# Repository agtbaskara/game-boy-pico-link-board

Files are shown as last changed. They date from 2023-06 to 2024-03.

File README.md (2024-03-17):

# USB TO GAMEBOY LINK CABLE ADAPTER
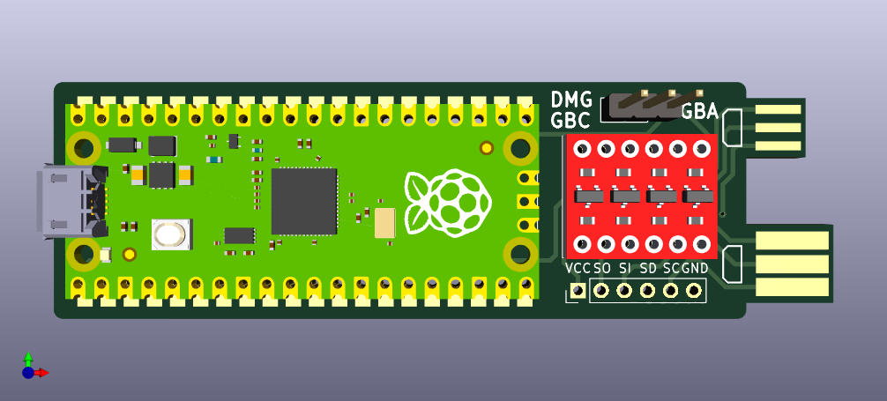
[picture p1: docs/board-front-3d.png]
Board 3D Render


An Open-Source USB to Gameboy Link Cable Adapter for Raspberry Pi Pico. Designed with components that are easy to source and solder.

Based on stacksmashing Gameboy Link adapter: https://www.youtube.com/watch?v=KtHu693wE9o

# Schematic

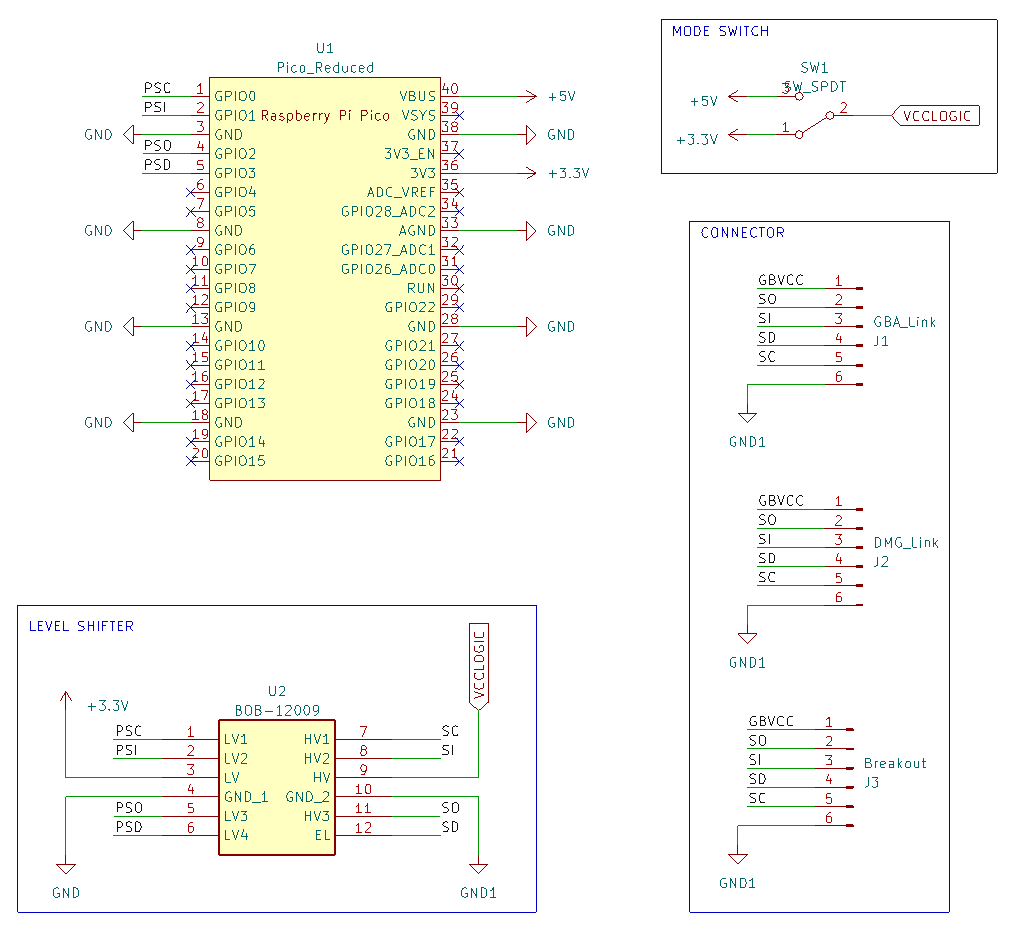
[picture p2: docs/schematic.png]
Schematic


# Required Components

| Reference | Part Number | Description |
|-|-|-|
| U1 | [Raspberry Pi Pico](https://www.raspberrypi.com/products/raspberry-pi-pico/) | Clones are compatible |
| U2 | [BOB-12009](https://www.sparkfun.com/products/12009) | Sparkfun Bi-Directional Logic Level Converter, clones are compatible |
| SW1 | [SS12D00-G3](https://www.amazon.com/Tnuocke-Vertical-Position-Switches-SS12D00-G3/dp/B099MRCDG8) | 3 Pin SPDT Switch with 1" (2.54mm) Pitch |

If you want to use pin jumper instead of switch you can use:

| Reference | Part Number | Description |
|-|-|-|
| SW1 | [Pin Header](https://www.amazon.com/dp/B07PKKY8BX) | 1x3 2.54mm Male Pin Header |
| - | [Pin Jumper](https://www.amazon.com/dp/B077957RN7) | 2.54mm Pin Jumper, harvest from old motherboard or hardrive |

**Attached links are for reference only, you can use any equivalent parts.**

**List of tested components** [Tested Components List](COMPONENTS.md)

# How to Order Board

To order a board, use the `gerbers.zip` from the release page or generate one yourself. You can order from your favourite PCB manufacturer ([JLCPCB](https://jlcpcb.com/), [PCBWay](https://www.pcbway.com/), etc.).

**Use 1.2mm PCB thickness.**

You can choose any colour for the Solder Mask and Silkscreen. For the Surface Finish, ENIG is recommended.

# How to Assemble Board

1. Trim the Link Cable connectors width on the board to the appropriate size using a file tool or sandpaper
2. Solder pin header to Raspberry Pi Pico and Level Shifter module. Use a breadboard for easier soldering
3. Solder Raspberry Pi Pico and Level Shifter module to the board
4. Cut the excessive pin using a nipper tool
5. Solder the 1x3 Pin Header to the board, and place the Pin Jumper
6. Flash firmware to your Raspberry Pi Pico (see [Compatibility](#Compatibility))

# How to Use Board

Connect the board to your PC, and connect the board to your Gameboy using a Link Cable.

For Gameboy/Gameboy Color game, place the pin jumper on the DMG/GBC side. For Gameboy Advance game, place the pin jumper on the GBA side.

**Be aware Gameboy/Gameboy Color mode uses 5V logic, while Gameboy Advance mode uses 3.3V logic. Make sure your pin jumper is placed on the correct side to avoid any damage.**

# Compatibility

This board is compatible with the following firmware:
- https://github.com/Lorenzooone/gb-link-firmware-reconfigurable (Recommended Firmware)
- https://github.com/stacksmashing/gb-link-firmware
- https://github.com/stacksmashing/gb-link-printer
- https://github.com/Lorenzooone/PokemonGB_Online_Trades
- https://github.com/dj505/GBPrinterEmu
- https://github.com/Squaresweets/GBPrinter-discord-bot
- https://github.com/KuestenKeks/pc-to-gb-printer

With some modification, it should be compatible with other firmware as well, such as:
- https://github.com/untoxa/pico-gb-printer

# References

- Raspberry Pi Pico Footprint: https://github.com/ncarandini/KiCad-RP-Pico
- Logic Level Converter (BOB-12009) Footprint: https://www.snapeda.com/parts/BOB-12009/SparkFun%20Electronics/view-part/
- Gameboy Link Connector Footprint: https://github.com/Palmr/gb-link-cable
- 1.2mm PCB Thickness, based on: https://hackaday.io/project/12932-game-link-online/log/43999-received-the-breakout-boards

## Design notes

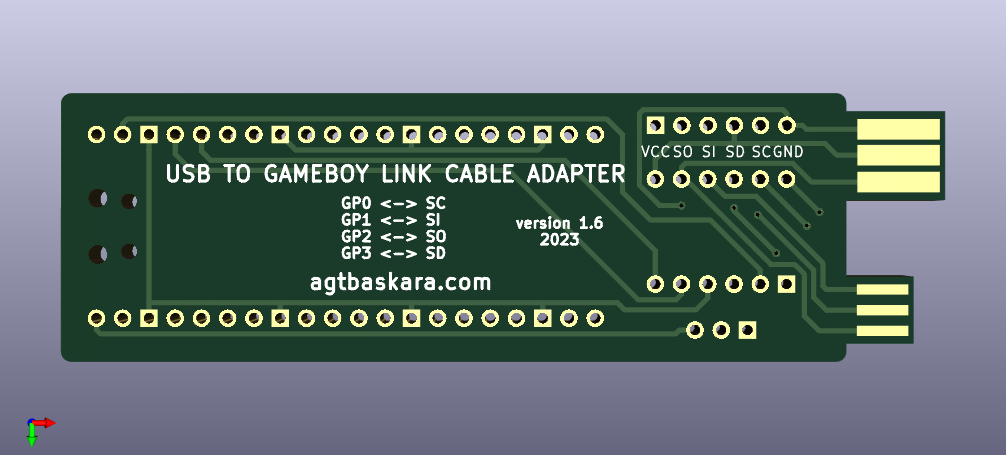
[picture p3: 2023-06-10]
docs/board-back-3d.png

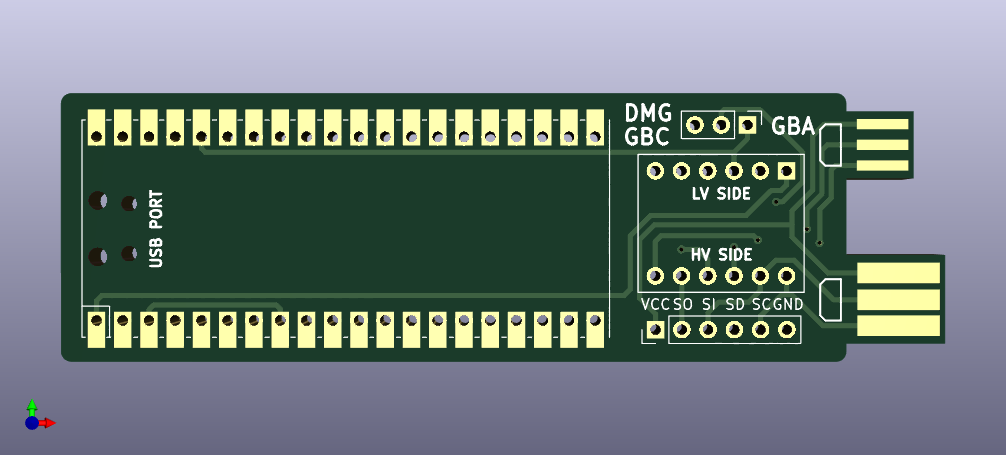
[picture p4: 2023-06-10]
docs/board-front-3d-bare.png

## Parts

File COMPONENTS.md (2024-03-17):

# Tested Components List

This page contains the components that have been tested with the adapter board. This page is based on my personal test and also data from the community.

Please contribute if you found new compatible/incompatible components.

## Raspberry Pi Pico

In theory every raspberry pi pico clones with the same pinout should work.

| Compatible | Pictures | Shop/Datasheet Link | Description |
|-|-|-|-|
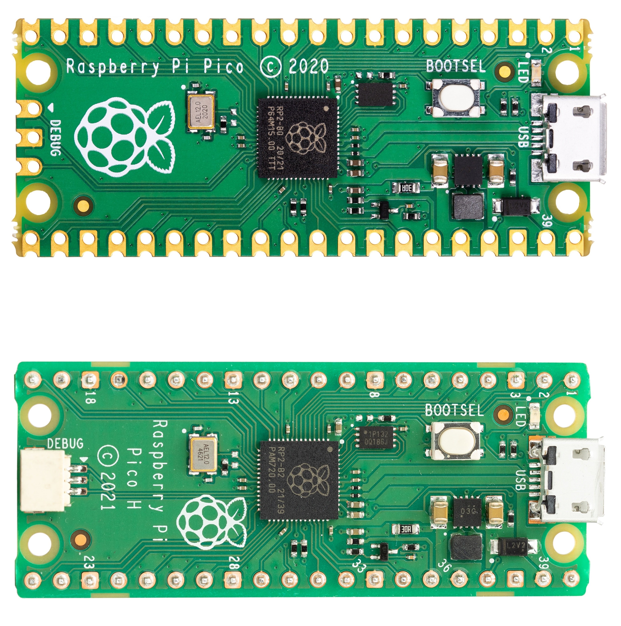
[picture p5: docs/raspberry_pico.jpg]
PICO
| Yes |  | [Link](https://www.raspberrypi.com/products/raspberry-pi-pico/) | Original Raspberry Pi Pico |
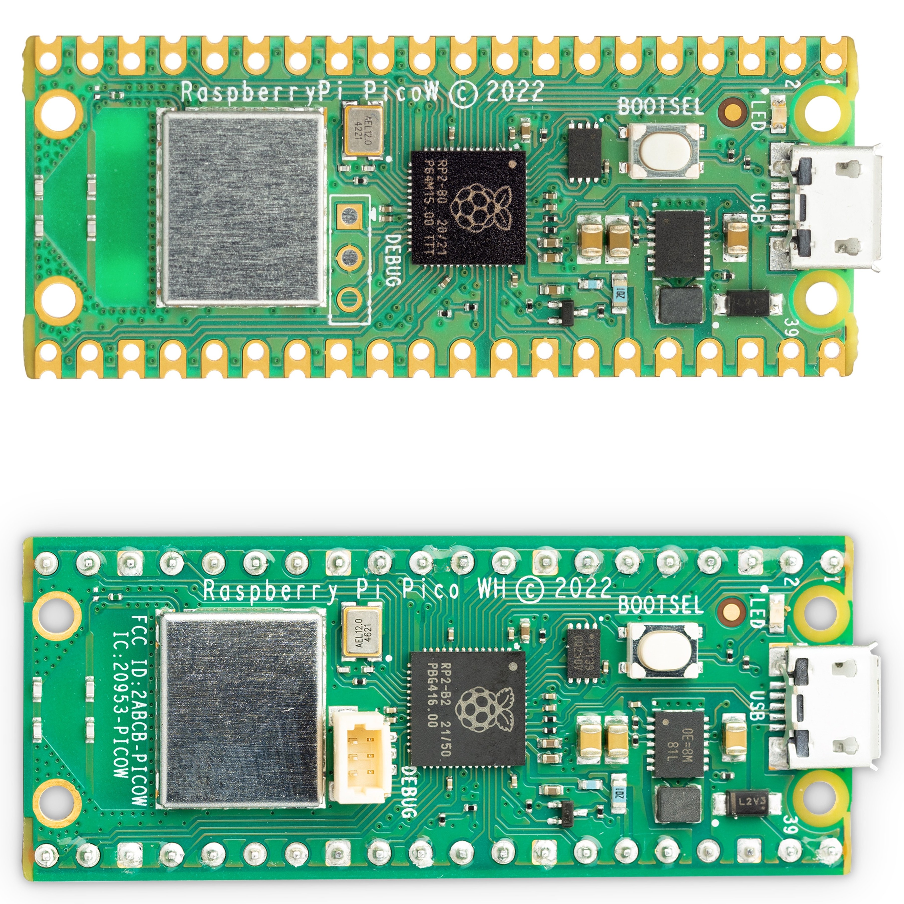
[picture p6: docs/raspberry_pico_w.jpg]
PICO
| Yes |  | [Link](https://www.raspberrypi.com/products/raspberry-pi-pico/) | Original Raspberry Pi Pico W|
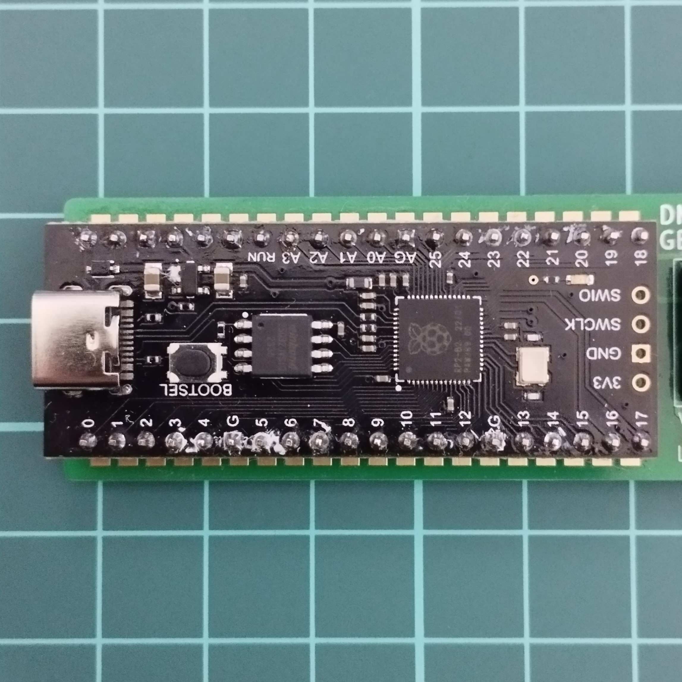
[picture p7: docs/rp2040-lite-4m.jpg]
| Yes |  | [Link](https://www.aliexpress.com/item/1005003928558306.html) | RP2040 Lite Black TYPE-C 4M|

## Level Shifter

Becareful of bad quality clones.

| Compatible | Pictures | Shop/Datasheet Link | Description |
|-|-|-|-|
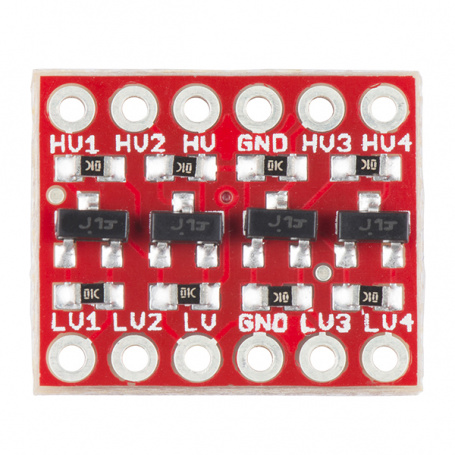
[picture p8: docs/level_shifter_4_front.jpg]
Level Shifter
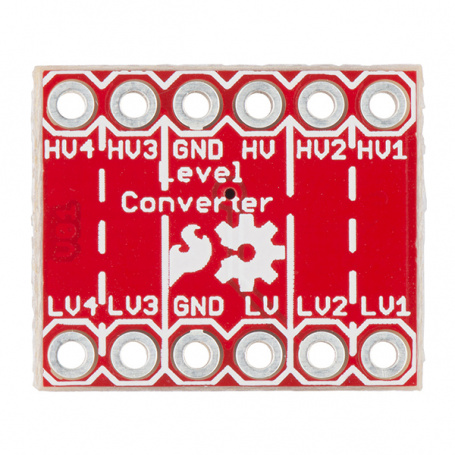
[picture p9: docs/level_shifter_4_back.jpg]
Level Shifter
| Yes |    | [Link](https://www.sparkfun.com/products/12009) | Original Sparkfun 4 Channel Level Shifter |
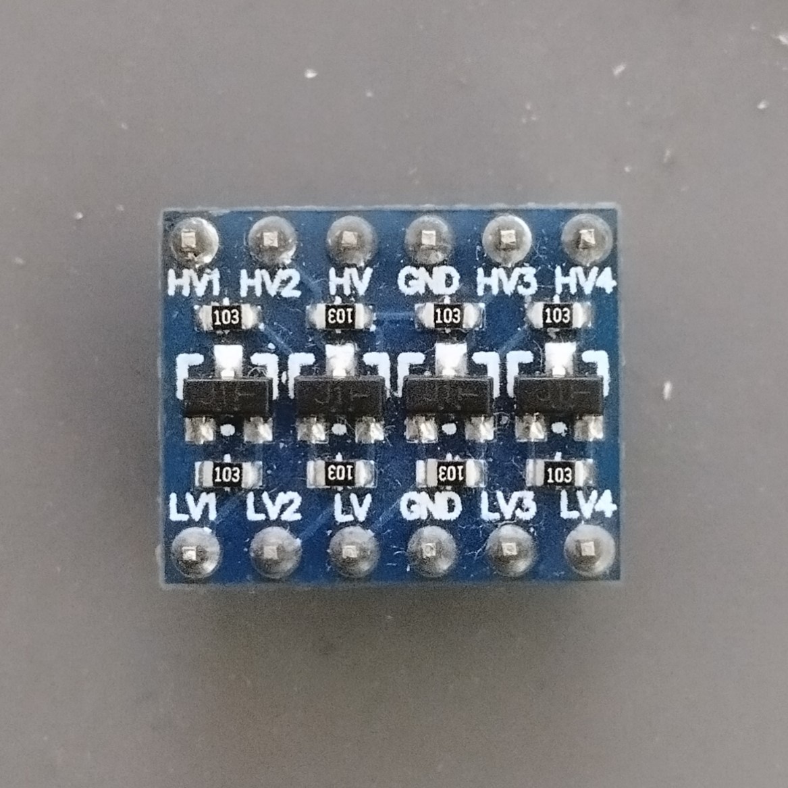
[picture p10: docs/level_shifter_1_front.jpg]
Level Shifter
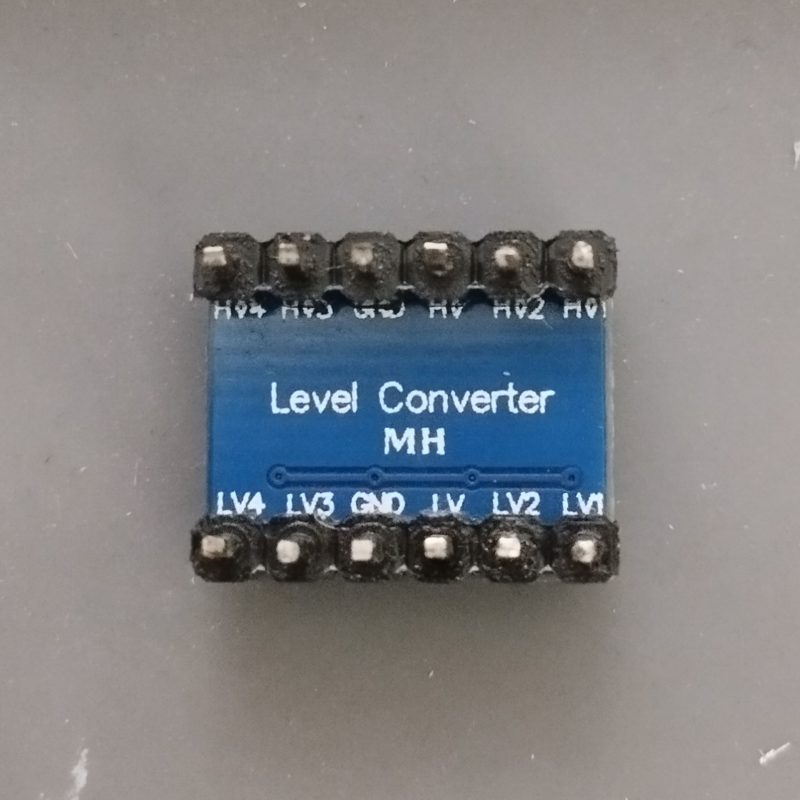
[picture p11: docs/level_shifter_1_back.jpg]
Level Shifter
| Yes |    |  |  |
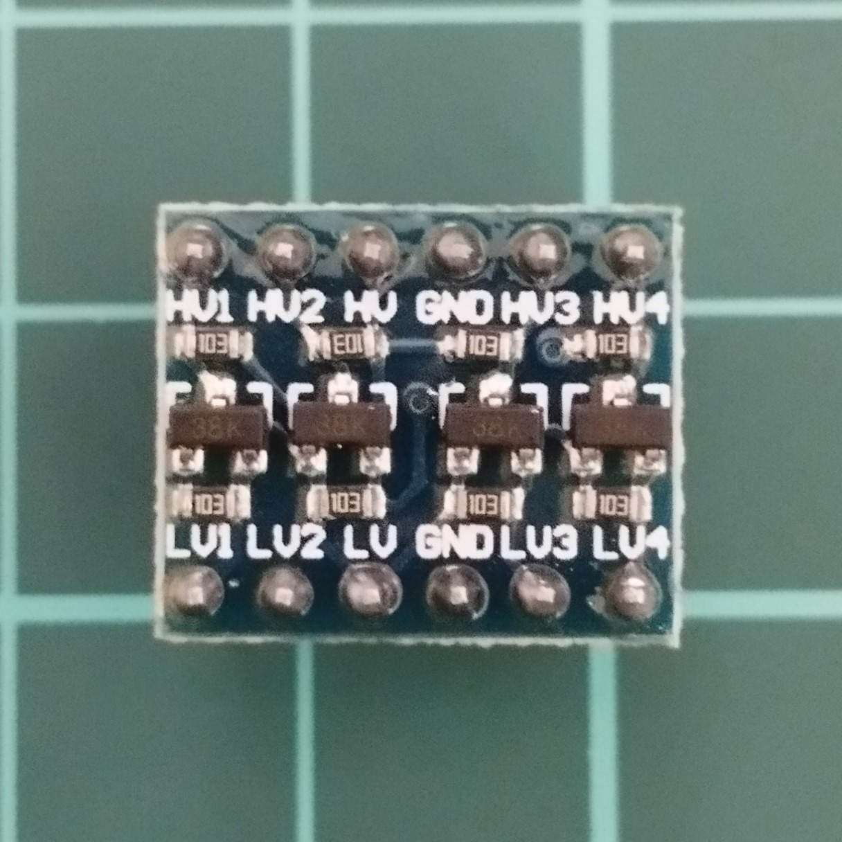
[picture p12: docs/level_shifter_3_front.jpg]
Level Shifter
| Yes |  Level Shifter  | [Link](https://www.amazon.co.jp/-/en/gp/product/B0CL2R6K26/) |  |
| No | Level Shifter Level Shifter  | [Link](https://www.amazon.co.jp/-/en/gp/product/B081RH1P4L) | Thin PCB, Low Quality Board |

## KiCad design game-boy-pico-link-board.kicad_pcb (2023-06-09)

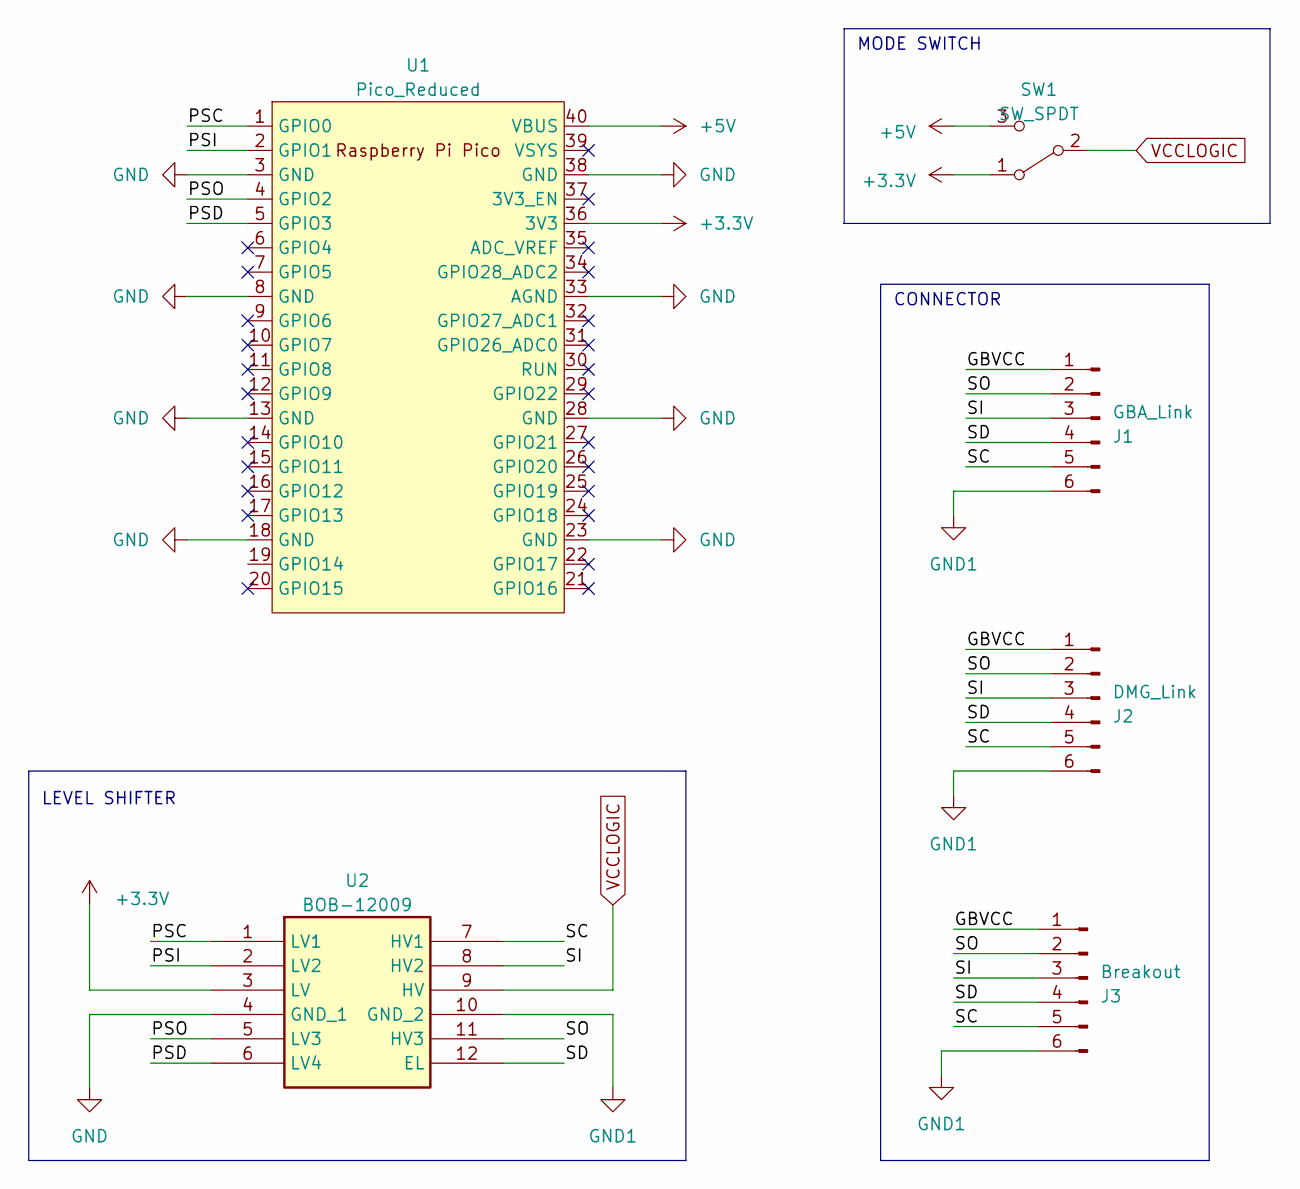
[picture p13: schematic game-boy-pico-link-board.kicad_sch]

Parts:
J1: GBA_Link; gb-link-socket
J2: DMG_Link; dmg-link-socket
J3: Breakout; PinHeader_1x06_P2.54mm_Vertical
SW1: SW_SPDT; PinHeader_1x03_P2.54mm_Vertical
U1: Pico_Reduced; RPi_Pico_SMD_TH_REDUCED
U2: BOB-12009

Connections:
+3.3V: SW1.1 (A), U1.36 (3V3), U2.3 (LV)
+5V: SW1.3 (C), U1.40 (VBUS)
/GBVCC: J1.1, J2.1, J3.1
/PSC: U1.1 (GPIO0), U2.1 (LV1)
/PSD: U1.5 (GPIO3), U2.6 (LV4)
/PSI: U1.2 (GPIO1), U2.2 (LV2)
/PSO: U1.4 (GPIO2), U2.5 (LV3)
/SC: J1.5, J2.5, J3.5, U2.7 (HV1)
/SD: J1.4, J2.4, J3.4, U2.12 (EL)
/SI: J1.3, J2.3, J3.3, U2.8 (HV2)
/SO: J1.2, J2.2, J3.2, U2.11 (HV3)
GND: U1.3 (GND), U1.8 (GND), U1.13 (GND), U1.18 (GND), U1.23 (GND), U1.28 (GND), U1.33 (AGND), U1.38 (GND), U2.4 (GND_1)
GND1: J1.6, J2.6, J3.6, U2.10 (GND_2)
VCCLOGIC: SW1.2 (B), U2.9 (HV)

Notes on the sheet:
LEVEL SHIFTER
MODE SWITCH
CONNECTOR

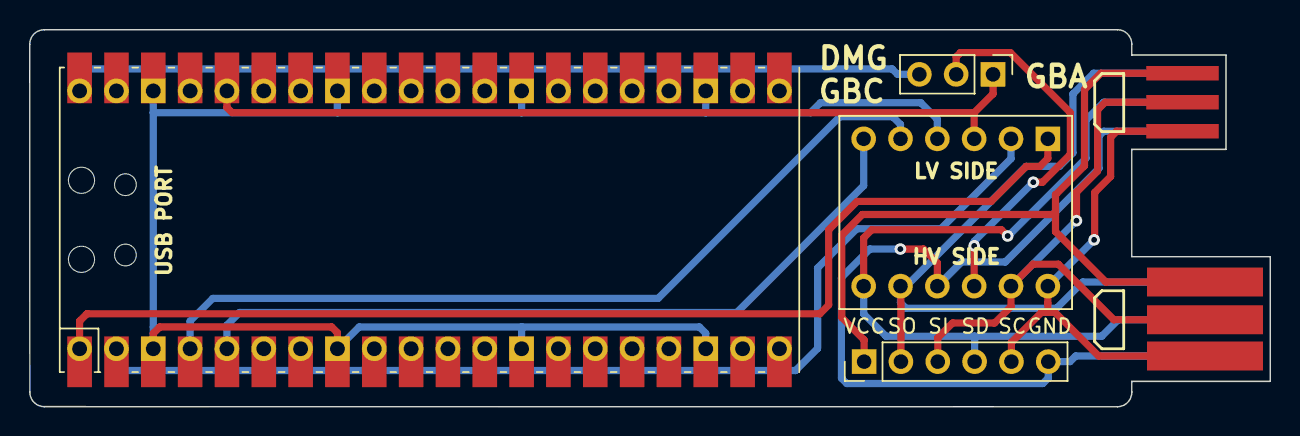
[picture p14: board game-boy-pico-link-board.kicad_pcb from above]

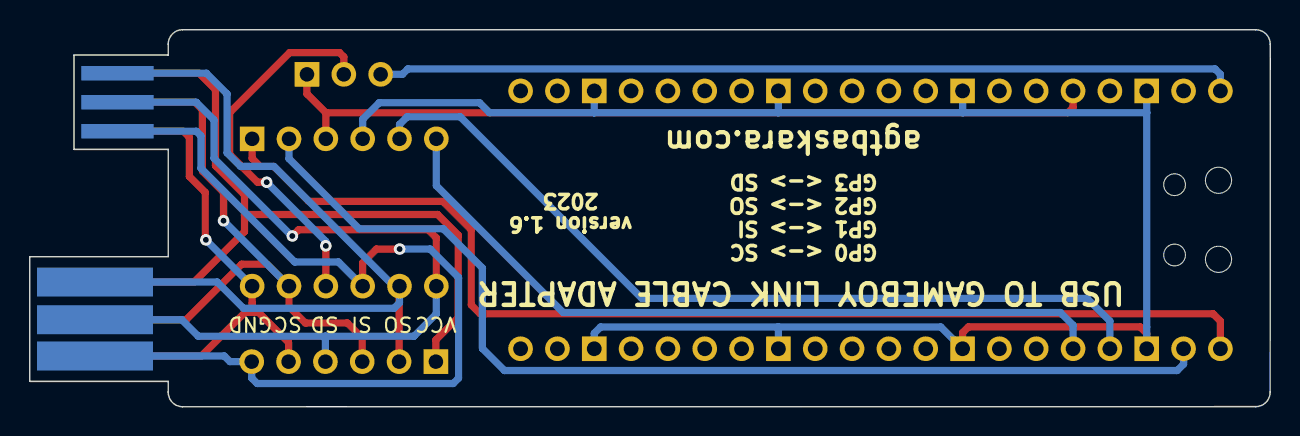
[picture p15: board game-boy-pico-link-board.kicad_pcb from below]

Board: 2 copper layers, 85.5 x 26.0 mm, 6 parts (2 on the bottom side), 14 nets.

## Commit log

2023-04-02 Add initial design
    [game-boy-pico-link-board.kicad_pcb, game-boy-pico-link-board.kicad_sch]
2023-05-27 Update Design and Add Routing
    [game-boy-pico-link-board.kicad_pcb, game-boy-pico-link-board.kicad_sch]
2023-05-27 Add gerbers file
    [game-boy-pico-link-board-B_Cu.gbl, game-boy-pico-link-board-B_Mask.gbs, game-boy-pico-link-board-B_Paste.gbp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]
2023-06-07 Update Design
    Shortened DMG socket
    Replace components layout
    Add more silkscreen text
    [game-boy-pico-link-board-B_Cu.gbl, game-boy-pico-link-board-B_Mask.gbs, game-boy-pico-link-board-B_Paste.gbp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]
2023-06-08 Update Connector Size
    Add extra 0.5mm padding on the connector width
    [game-boy-pico-link-board-B_Cu.gbl, game-boy-pico-link-board-B_Mask.gbs, game-boy-pico-link-board-B_Paste.gbp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]
2023-06-08 Update gerbers file
    [game-boy-pico-link-board-B_Cu.gbl, game-boy-pico-link-board-B_Mask.gbs, game-boy-pico-link-board-B_Paste.gbp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]
2023-06-09 Minor rerouting
    Update design to v1.6
    [game-boy-pico-link-board-B_Cu.gbl, game-boy-pico-link-board-B_Mask.gbs, game-boy-pico-link-board-B_Paste.gbp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]
2023-10-28 Update readme: replace pin jumper with switch
2023-12-02 Fix missing no-connection flag
    [game-boy-pico-link-board.kicad_sch]
